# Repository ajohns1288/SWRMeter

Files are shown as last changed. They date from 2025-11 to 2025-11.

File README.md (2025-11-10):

# SWRMeter
PCB files, 3D printing files, and Arduino program to replace the traditional crossed needles SWR meter.

This project was originally done to replace the crossed needle meter on my LDG AT-11MP Tuner, as the meter was broken and replacement parts no longer available.



# To Calibrate
1: Compile with _CALIBRATE_SHOW_COUNTS == 1

2: Attach meter to DUT, transmit into dummy load using FM at 5W and record number on display.

3: Repeat for power values listed in LUT_FWD[] (you can extrapolate if your transmitter only goes so high)

4: Transmit backwards (INTO antenna port with dummy load on TX port) and record number for Ref Pwr. (May want to limit power and extrapolate)

5: Enter recorded values into LUT_FWD[] and LUT_REF[], set _CALIBRATE_SHOW_COUNTS == 0, and compile.

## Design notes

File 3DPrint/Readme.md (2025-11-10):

# 3D Print Files
Both the STLs and FreeCAD FCStd are prpvided

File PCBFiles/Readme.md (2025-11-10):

# PCB Files
This should be everything needed to get a PCB fabbed.

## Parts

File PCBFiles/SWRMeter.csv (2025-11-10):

Comment | Designator | Footprint
10 | R10,R9 | R_0603_1608Metric
0.1u | C10,C9,C8,C7,C4 | C_0603_1608Metric
INA190A1 | U4,U3 | SOT-363_SC-70-6_Handsoldering
10k | R8,R7 | R_0603_1608Metric
500 | R6,R5 | R_0603_1608Metric
22n | C6,C5 | C_0603_1608Metric
AMS1117-5.0 | U1 | SOT-223-3_TabPin2
500 | RV2,RV1 | Potentiometer_Bourns_3314J_Vertical
100 | R4,R3,R2,R1 | R_0603_1608Metric
10u | C3,C2,C1 | CP_EIA-3216-12_Kemet-S

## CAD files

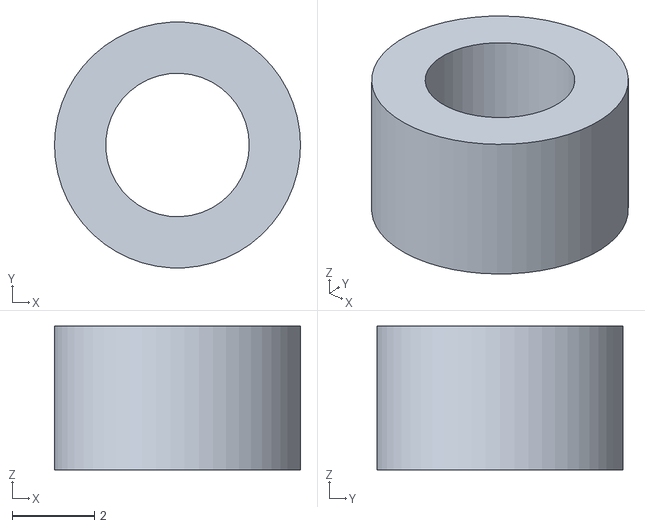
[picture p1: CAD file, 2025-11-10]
3DPrint/SWR-MeterSpacer.stl
6.00 x 5.99 x 3.50

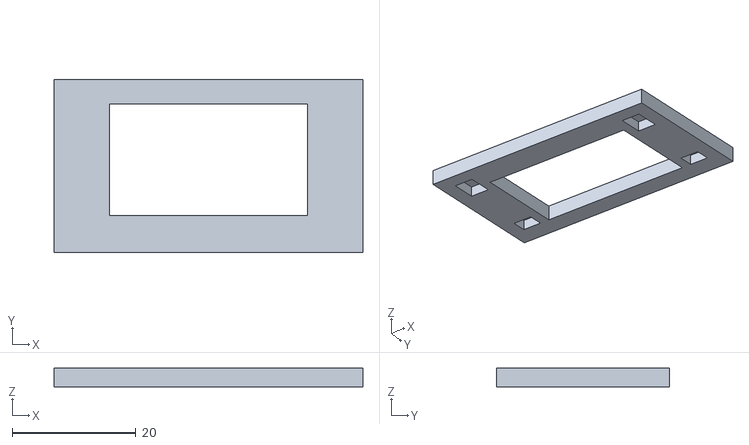
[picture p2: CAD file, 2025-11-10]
3DPrint/SWR-MeterFt.stl
50.0 x 28.0 x 3.00

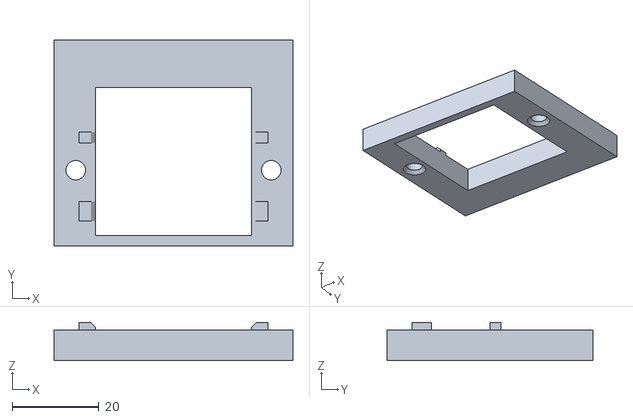
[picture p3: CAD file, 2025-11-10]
3DPrint/SWR-MeterBody.stl
55.0 x 47.5 x 8.75

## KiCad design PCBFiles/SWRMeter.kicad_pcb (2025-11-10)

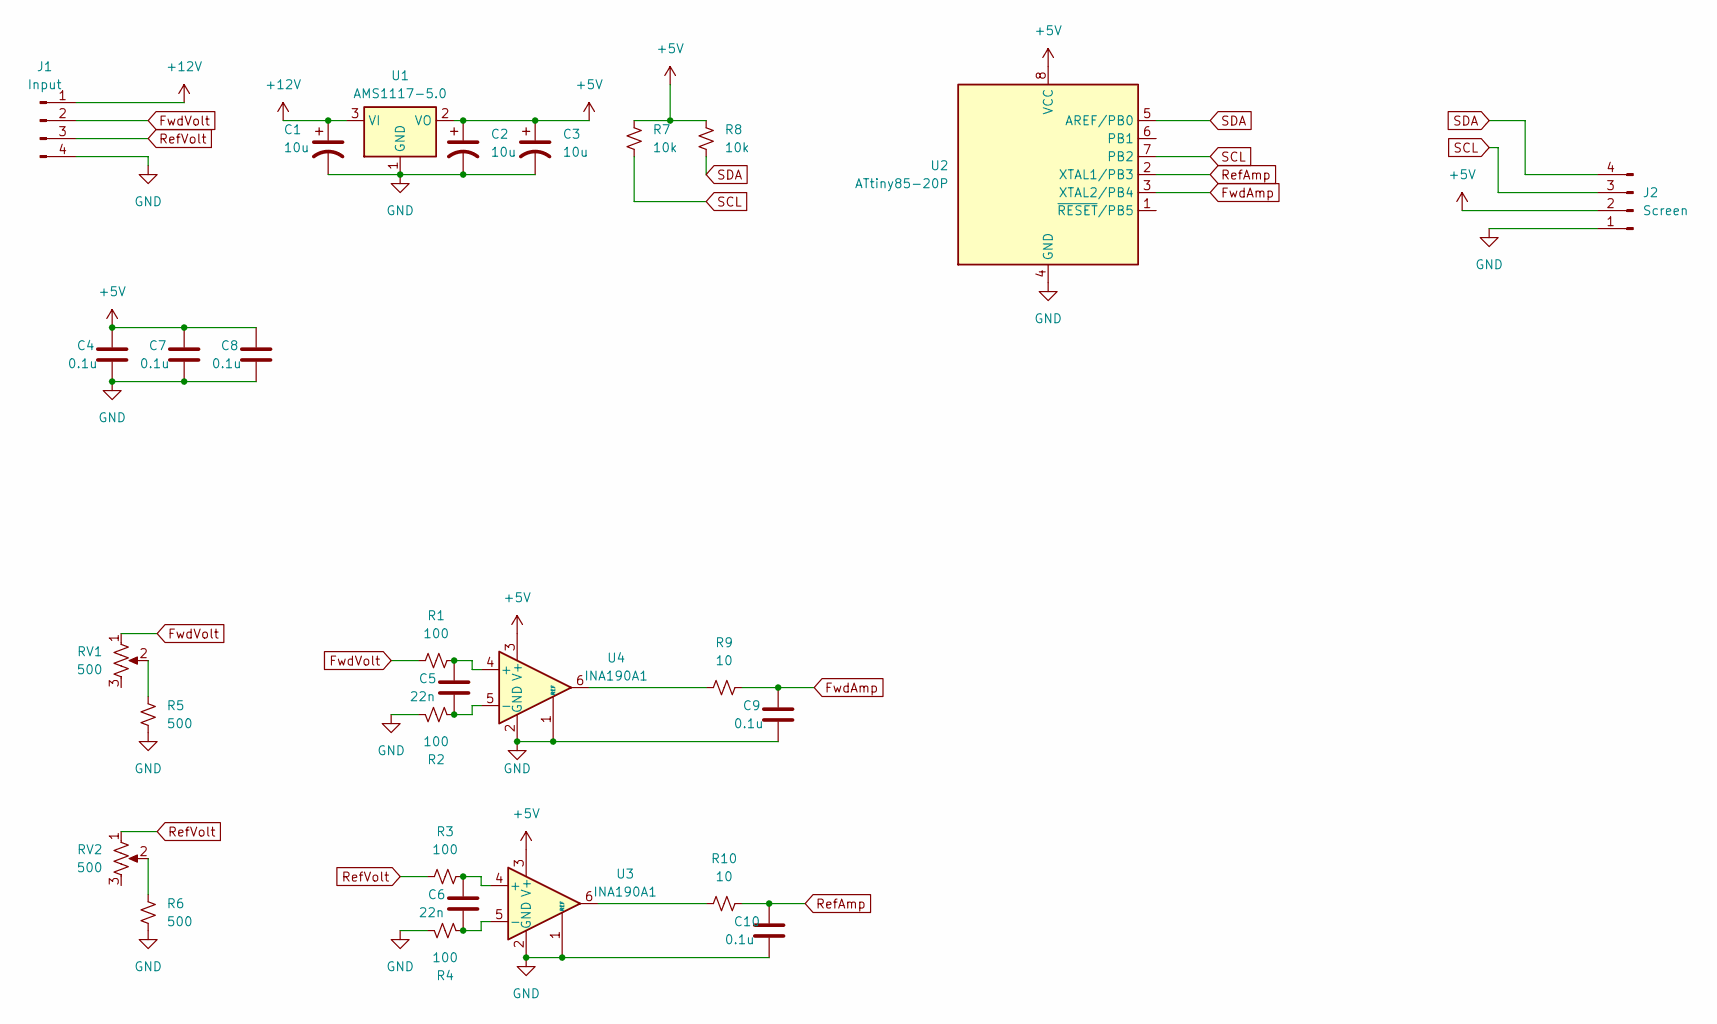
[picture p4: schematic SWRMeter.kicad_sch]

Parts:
C1, C2, C3: 10u; CP_EIA-3216-12_Kemet-S
C4, C7, C8, C9, C10: 0.1u; C_0603_1608Metric
C5, C6: 22n; C_0603_1608Metric
J1: Input; PinHeader_1x04_P2.54mm_Vertical
J2: Screen; PinHeader_1x04_P2.54mm_Vertical
R1, R2, R3, R4: 100; R_0603_1608Metric
R5, R6: 500; R_0603_1608Metric
R7, R8: 10k; R_0603_1608Metric
R9, R10: 10; R_0603_1608Metric
RV1, RV2: 500; Potentiometer_Bourns_3314J_Vertical
U1: AMS1117-5.0; SOT-223-3_TabPin2
U2: ATtiny85-20P; DIP-8_W7.62mm
U3, U4: INA190A1; SOT-363_SC-70-6_Handsoldering

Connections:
+5V: C2.1, C3.1, C4.2, C7.2, C8.2, J2.2, R7.1, R8.1, U1.2 (VO), U2.8 (VCC), U3.3 (V+), U4.3 (V+)
+12V: C1.1, J1.1, U1.3 (VI)
FwdAmp: C9.2, R9.2, U2.3 (XTAL2/PB4)
FwdVolt: J1.2, R1.1, RV1.1
GND: C1.2, C2.2, C3.2, C4.1, C7.1, C8.1, C9.1, C10.1, J1.4, J2.1, R2.1, R4.1, R5.2, R6.2, U1.1 (GND), U2.4 (GND), U3.1 (REF), U3.2 (GND), U4.1 (REF), U4.2 (GND)
unnamed: R5.1, RV1.2
unnamed: R6.1, RV2.2
unnamed: R9.1, U4.6
unnamed: R10.1, U3.6
unnamed: C6.2, R3.2, U3.4 (+)
unnamed: C6.1, R4.2, U3.5 (-)
unnamed: C5.2, R1.2, U4.4 (+)
unnamed: C5.1, R2.2, U4.5 (-)
RefAmp: C10.2, R10.2, U2.2 (XTAL1/PB3)
RefVolt: J1.3, R3.1, RV2.1
SCL: J2.3, R7.2, U2.7 (PB2)
SDA: J2.4, R8.2, U2.5 (AREF/PB0)

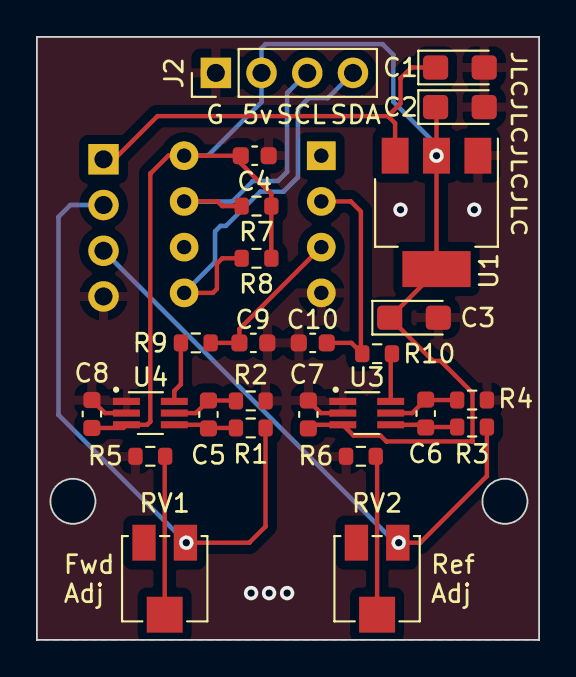
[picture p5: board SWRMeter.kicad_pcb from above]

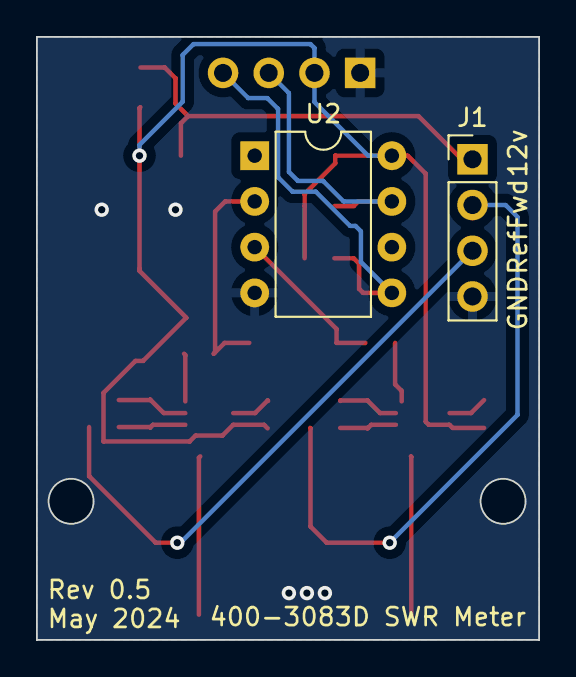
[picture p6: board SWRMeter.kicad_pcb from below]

Board: 2 copper layers, 27.9 x 33.5 mm, 28 parts (2 on the bottom side), 17 nets.

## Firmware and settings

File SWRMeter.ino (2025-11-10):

/*
  Project: Digital SWR/Power Meter
  SWRMeter.ino: Code that reads voltages, calculates power/SWR based on those voltages, then displays on screen

  NOTE: This was designed to run on an ATTiny85 with the latest ATTiny core. It will not compile without the latest ATTinyCore.

    Copyright (C) 2024, Andrew Johnson AJohns1288@Gmail.com

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
    You should have received a copy of the GNU General Public License
    along with this program.  If not, see <https://www.gnu.org/licenses/>.
*/

//Include needed files
#include "TinySH1106.h" //Display library
#include "font.h" //Fonts for display library
#include "LUT.h"  //Lookup table function 

//Flag to display counts instead of power. Used for setting the calibration curve
#define _CALIBRATE_SHOW_COUNTS 0

//Hardware defines/////////////////////////
//Pins to use for measurement
#define FWD_PWR_PIN A2
#define REF_PWR_PIN A3

//Voltage limits
#define MIN_VAL 8  //Min clip on voltage, in ADC counts
///////////////////////////////////////////


//DSP defines//////////////////////////////
//Note: These DSP functions were put in as an experimental exercise. They can be adjusted as needed

#define _DSP_USE_MULTI_SAMPLE 1   //Enabled: ADC read takes 5 samples, excludes extremes, and averages for each reading. Disabled: One sample per reading
#define _DSP_USE_WINDOW_AVG 1     //Enabled: ADC read is averaged across previous 5 readings. Disabled: ADC read is not averaged (Averaging takes place after read)
#define _DSP_USE_EWMA_FILTER 1    //Enabled: ADC read is filtered. Disabled: ADC read is not filtered. (Filtering takes place after averaging)
#define _DSP_USE_ADC_NOISE_RED 1  //Enabled: ADC reads will use the noise reduction feature (sleep during conversion), Disabled: ADC reads will occur with all CPU running
#define _DSP_USE_DITHER 1         //Enabled: ADC is read twice in a row, one bit is added, then sum divded by 2. This helps with single bit noise, Disabled: ADC is read once.
#define _DSP_PEAK_HOLD_TIME 3000  //Amount of time, in ms, that the peak value will be held on the display
#define _DSP_PEAK_HOLD_DEC 50     //Rate that the display value will decay to the current value after the hold time expires
#define ADC_TIME 250              //Minimum sample rate, in us, that the ADCs are read. Note that this is the minimum, actual readings may take longer.

//Filter constants for EWMA filter in fixed 10e-1 point(8=0.800)
#define FWD_FILTER_CONST 3
#define REF_FILTER_CONST 3
////////////////////////////////////////////


//Display defines///////////////////////////
//Full scale power in watts
#define FWD_PWR_FS 300
#define REF_PWR_FS 60

//Screen Refresh Rate
#define UPDATE_TIME 250  //In milliseconds
////////////////////////////////////////////

#if _DSP_USE_ADC_NOISE_RED
#include <avr/sleep.h>  // Sleep Modes
EMPTY_INTERRUPT(ADC_vect);
#endif


//Calibration table for FWD Pwr (counts to Watts x10)
const unsigned int LUT_FWD[] PROGMEM= {10, \
                10, 0, \
                88, 5, \
                118, 10, \
                180, 30, \
                213, 40, \
                273, 60, \
                300, 70, \
                350, 90, \
                695, 200, \
                1000, 300
              };

//Calibration table for Ref Pwr (counts to Wattsx10)
const unsigned int LUT_REF[] PROGMEM= {10, \
                10, 00, \
                88, 10, \
                118, 20, \
                180, 60, \
                213, 80, \
                273, 120, \
                300, 140, \
                350, 180, \
                695, 400, \
                1000, 600
              };


//Display object
TinySH1106 display(0x3c);

//char constant buffers
const char text_FWD[] = { 'F', 'W', 'D', 0x20 };
const char text_REF[] = { 'R', 'E', 'F', 0x20 };
const char text_PWR[] = { 'P', 'W', 'R', ':', 0x20, 0 };
const char text_SWR[] = { 'S', 'W', 'R', ':', 0x20, 0 };

//Char buffers for display values
char buf_PWR_val[] = { 0x20, 0x20, 0x20, 0x20, 0 };
char buf_REF_val[] = { 0x20, 0x20, 0x20, 0x20, 0 };
char buf_SWR_val[] = { '1', '.', '0', '0', 0 };

//Instantaneous/filtered ADC reads (in counts)
int fwdPwrInst = 0;
int refPwrInst = 0;
int fwdPwrFilt = 0;
int refPwrFilt = 0;

//Filter buffer - Compile the buffers out to save memory if unused
#if _DSP_USE_MULTI_SAMPLE
int filtBuf[] = { 0, 0, 0, 0, 0 };
#endif

//Windowed Average buffer - Compile the buffers out to save memory if unused
#if _DSP_USE_WINDOW_AVG
int fwdAvgBuf[] = { MIN_VAL, MIN_VAL, MIN_VAL, MIN_VAL, MIN_VAL };
int refAvgBuf[] = { MIN_VAL, MIN_VAL, MIN_VAL, MIN_VAL, MIN_VAL };
uint8_t avgIndx = 0;
#endif

//Display values - integer representation
int swrVal = 100;    //SWR x 100
int fwdDispVal = 0;  //Watts x1
int refDispVal = 0;  //Watts x1

//Timers
long dispUpdateTmr = 0; //Display refresh rate
long ADCTmr = 0; //ADC Sample rate
long FWDPeakHold=0; //Peak hold for FWD power
long REFPeakHold=0; //Peak hold for reflected power.


void setup() {

  analogRead(FWD_PWR_PIN); //Initialize A2D

  //Start display and set up splash screen
  display.begin();
  display.clear();
  splash();
  delay(1000);
  display.clear();

  //Set up static parts of display
  display.setCursor(0, 0);
  display.print(text_FWD);
  display.setCursor(40, 0);
  display.print(text_PWR);
  display.setCursor(0, 2);
  display.print(text_REF);
  display.setCursor(40, 2);
  display.print(text_PWR);
  display.setCursor(16, 6);
  display.print(text_SWR);
}

void loop() {
  //Update display if it is time
  if (millis() - dispUpdateTmr > UPDATE_TIME) {
    dispUpdateTmr = millis(); //Reset timer

    swrVal = getSWR(fwdDispVal, refDispVal); //Ger SWR value from fwd and ref powers


    //If we are in calibration mode, set display value to ADC counts (only last 3 digits will show)
    #if _CALIBRATE_SHOW_COUNTS
    fwdDispVal = fwdPwrFilt;
    refDispVal = refPwrFilt;
    #else
    //If we are in normal mode, convert voltage to power
    voltToPwr();
    #endif

    //Update screen with updated values
    updateScreen();
  }


  //Sample ADC if it is time
  if(micros()-ADCTmr>ADC_TIME)
  {
    ADCTmr=micros();
    readPwrADC();
  }
  
}

void swr2Char(int i, char *buf) {
  
  //Get the character that corresponds with each place in the input
  char ones = i % 10 + 0x30;
  char tens = (i / 10) % 10 + 0x30;
  char hund = (i / 100) % 10 + 0x30;

  //set the text buffers based on how big the SWR is
  if (i < 100) {
    buf[0] = 'E';
    buf[1] = 'R';
    buf[2] = 'R';
    buf[3] = 0x20;
  } else if (i >= 600) {
    buf[0] = 'H';
    buf[1] = 'I';
    buf[2] = 0x20;
    buf[3] = 0x20;
  } else {
    buf[0] = hund;
    buf[1] = '.';
    buf[2] = tens;
    buf[3] = ones;
  }
}

void pwr2Char(int i, char *buf) {
  
  //Get the character that corresponds with each place in the input
  char ones = i % 10 + 0x30;
  char tens = (i / 10) % 10 + 0x30;
  char hund = (i / 100) % 10 + 0x30;


  //set the buffers based on how big the power is
  if (i < 10) {
    buf[0] = ones;
    buf[1] = 'W';
    buf[2] = 0x20;
    buf[3] = 0x20;
  } else if (i < 100) {
    buf[0] = tens;
    buf[1] = ones;
    buf[2] = 'W';
    buf[3] = 0x20;
  } else {
    buf[0] = hund;
    buf[1] = tens;
    buf[2] = ones;
    buf[3] = 'W';
  }
}

void splash() {
  display.drawBitmap(bitmap1, 40, 18);
}

void updateScreen() {
  //Convert values to corresponding characters
  pwr2Char(fwdDispVal, buf_PWR_val);
  pwr2Char(refDispVal, buf_REF_val);
  swr2Char(swrVal, buf_SWR_val);

  //Set print position and print the updated characters
  display.setCursor(81, 2);
  display.print(buf_REF_val);
  display.setCursor(81, 0);
  display.print(buf_PWR_val);
  display.setCursor(52, 6);
  display.print(buf_SWR_val);
}

int getADCReading(byte port) 
{

  //Wrapper function to get ADC readings
  //ATTinycore's newest version allows analogRead to use the onboard ADC noise reduction function
  //If dithering is turned on, function will take two readings, add a bit, then divide by two. This has the affect of helping with single bit noise

//Variable to store first read when using dithering  
int read1=0;

//If ATTIny, use the noise reduction read in newest ATTiny core.
#if (AVR_ARCH==2||AVR_ARCH==25)
  #if _DSP_USE_DITHER
  read1=_analogRead(port, _DSP_USE_ADC_NOISE_RED);
  return (read1+_analogRead(port, _DSP_USE_ADC_NOISE_RED))+1)/2;
  #else
  return _analogRead(port, _DSP_USE_ADC_NOISE_RED);
  #endif
#else
//For Normal arduino, ADC noise reduction not possible
  #if _DSP_USE_DITHER
  read1=analogRead(port);
  return (read1+analogRead(port)+1)/2;
  #else
  return analogRead(port);
  #endif
#endif
 //End _DSP_USE_ADC_NOISE_RED
}

void readPwrADC() {
//function to read in voltages and filter them
#if _DSP_USE_MULTI_SAMPLE

  int maxRead = 0;
  int minRead = 1024;

  for (int i = 0; i < 5; i++) {
    fwdPwrInst = getADCReading(FWD_PWR_PIN);
    filtBuf[i] = fwdPwrInst;

    if (fwdPwrInst > maxRead) {
      maxRead = fwdPwrInst;
    } else if (fwdPwrInst < minRead) {
      minRead = fwdPwrInst;
    }
  }
  fwdPwrInst = ((filtBuf[0] + filtBuf[1] + filtBuf[2] + filtBuf[3] + filtBuf[4]) - minRead - maxRead) / 3;

  //Reset min/max
  maxRead = 0;
  minRead = 1024;
  for (int i = 0; i < 5; i++) {
    refPwrInst = getADCReading(REF_PWR_PIN);
    filtBuf[i] = refPwrInst;

    if (refPwrInst > maxRead) {
      maxRead = refPwrInst;
    } else if (refPwrInst < minRead) {
      minRead = refPwrInst;
    }
  }
  refPwrInst = ((filtBuf[0] + filtBuf[1] + filtBuf[2] + filtBuf[3] + filtBuf[4]) - minRead - maxRead) / 3;


#else  //just take one sample
  fwdPwrInst = getADCReading(FWD_PWR_PIN);
  refPwrInst = getADCReading(REF_PWR_PIN);
#endif

#if _DSP_USE_WINDOW_AVG
//Window average the last 5 samples excluding outliers
  fwdAvgBuf[avgIndx] = fwdPwrInst;
  refAvgBuf[avgIndx] = refPwrInst;

  avgIndx > 4 ? avgIndx = 0 : avgIndx++;

  int minRef = refAvgBuf[0];
  int maxRef = refAvgBuf[0];
  int minFwd = fwdAvgBuf[0];
  int maxFwd = fwdAvgBuf[0];

  int refSum = refAvgBuf[0];
  int fwdSum = fwdAvgBuf[0];

  for (int i = 1; i < 5; i++) {
    maxRef = max(refAvgBuf[i], maxRef);
    minRef = min(refAvgBuf[i], minRef);

    maxFwd = max(fwdAvgBuf[i], maxFwd);
    minFwd = min(fwdAvgBuf[i], minFwd);

    fwdSum += fwdAvgBuf[i];
    refSum += refAvgBuf[i];
  }

  refPwrInst = (refSum - minRef - maxRef) / 3;
  fwdPwrInst = (fwdSum - minFwd - maxFwd) / 3;
#endif // End USE_WINDOW_AVG

#if _DSP_USE_EWMA_FILTER
  //EWMA filter using integer math (alpha x10)
  fwdPwrFilt = (FWD_FILTER_CONST * fwdPwrInst) + ((10 - FWD_FILTER_CONST) * fwdPwrFilt);
  refPwrFilt = (REF_FILTER_CONST * refPwrInst) + ((10 - REF_FILTER_CONST) * refPwrFilt);
  //divide by 10 because we scaled up by 10 for the lines above
  fwdPwrFilt /= 10;
  refPwrFilt /= 10;
#else  //No filtering, just use instantaneous value
  fwdPwrFilt = fwdPwrInst;
  refPwrFilt = refPwrInst;
#endif
}

int voltToPwr()
{
  //Variable to hold lookup table result.
  int tmp=0;
  
  //If filtered power voltage value is over the min voltage, look up voltage in table, otherwise set power to 0
  (refPwrFilt<MIN_VAL)?refDispVal = 0:tmp = lookupTable(LUT_REF,refPwrFilt);


  //Peak and hold function
  if(tmp>refDispVal)//If current reading greater than whats on display
  {
    refDispVal=tmp; //Set display value if current reading is higher
    REFPeakHold=millis(); //Restart timer
  }
  else if(millis()-REFPeakHold>_DSP_PEAK_HOLD_TIME) //If current reading less than display and hold time expires
  {
    refDispVal-=_DSP_PEAK_HOLD_DEC; //Decrement display value by calibratable amount
    refDispVal=max(refDispVal,tmp); //Set display value to max of decremented value or current reading.
  } //Otherwise do nothing (leave display value as is)

  //If filtered power voltage value is over the min voltage, look up voltage in table, otherwise set power to 0
  (fwdPwrFilt<MIN_VAL)?fwdDispVal = 0:tmp = lookupTable(LUT_FWD,fwdPwrFilt);


  //Peak and hold function for Fwd power
  if(tmp>fwdDispVal)
  {
    fwdDispVal=tmp;
    FWDPeakHold=millis();
  }
  else if(millis()-FWDPeakHold>_DSP_PEAK_HOLD_TIME)
  {
    fwdDispVal-=_DSP_PEAK_HOLD_DEC;
    fwdDispVal=max(fwdDispVal,tmp);
  }

}


int getSWR(int fwdPwr, int refPwr) {
  //calculate the SWR without using floats, returns SWR x 100.
  if (refPwr * 2 > fwdPwr) {
    return 600;  //just send 6 if SWR is too high;
  } else if (refPwr == 0) {
    return 100;  //send 1 if no reflected power
  }


  //Calculate reflection coeff - We rescale by 1024 and 100 to get more precision in the sqrt function, since we are using fixed point math
  //Note that 1024 and 100 rescales will change to 32 and 10 after the square root due to distributive property.
  unsigned int tmp = (refPwr * 1024) / fwdPwr;  //rescale by 1024 (32^2)
  tmp = 100 * tmp;                              //rescale by 100 (10^2)
  tmp = intSqrt(tmp);                           // this will give you closest integer sqrt of the rescaled value above
  tmp = tmp * 100;                              //rescale by another 100 (+10*32 from before sqrt)
  tmp = tmp / 32;                               //this gives reflection coef *1000

  //SWR = (1+gamma)/(1-gamma) (x1000 due to scale above)
  unsigned int swrNum = (10 * (1000 + tmp));  //1 +gamma term
  return swrNum / ((1000 - tmp) / 10);        //divde by 1-gamma term
}

unsigned int intSqrt(int s) {
  //quick and dirty sqrt function to avoid floats
  int guess = (s >> 7) + 6;  //pick initial guess based on s

  for (uint8_t i = 0; i < 4; i++) { //4 iterations of newtons method to get approximate square root.
    guess = (guess + (s / guess));  //newtons method
    guess >>= 1;                    //divide by 2
  }

  return guess;
}

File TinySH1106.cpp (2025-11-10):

/*
  Project: Digital SWR/Power Meter
  TinySH1106.cpp: Library to interface with SH1106. Goal is to minimize RAM usage to be compatable with ATTiny
  Andrew Johnson AJohns1288@Gmail.com

  Adapted from:
  Tiny Graphics Library v3 - see http://www.technoblogy.com/show?23OS
  David Johnson-Davies - www.technoblogy.com - 23rd September 2018

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
    You should have received a copy of the GNU General Public License
    along with this program.  If not, see <https://www.gnu.org/licenses/>.
*/

#include "TinySH1106.h"
#include "font.h"

char TinySH1106::ReverseByte (char x) {
  x = ((x >> 1) & 0x55) | ((x << 1) & 0xaa);
  x = ((x >> 2) & 0x33) | ((x << 2) & 0xcc);
  x = ((x >> 4) & 0x0f) | ((x << 4) & 0xf0);
  return x;    
}

void TinySH1106::initDisplay () {
  sendCommand(DISPLAY_OFF); 
  sendCommand(SEG_REMAP_REV);  // Flip horizontal
  sendCommand(SET_SCAN_DEC);  // Flip horizontal
  sendCommand(DISPLAY_ON);  // Display on
  setMuxRatio(0x3F);
  setContrast(0xCF);
  setOffset(DEFAULT_OFFSET);
}

// Plot point x,y into buffer if in current slice
// void TinySH1106::PlotPoint (int x, int y) {
//   Wire.beginTransmission(wireAddr);
//   sendCommand(0x00 + ((x + 2) & 0x0F));        // Column low nibble
//   sendCommand(0x10 + ((x + 2)>>4));            // Column high nibble
//   sendCommand(0xB0 + (y >> 3));                // Page
//   sendCommand(0xE0);                           // Read modify write
//   Wire.write(SINGLE_DATA);
//   Wire.endTransmission();
//   Wire.requestFrom(wireAddr, 2);
//   Wire.read();                            // Dummy read
//   int j = Wire.read();
//   Wire.beginTransmission(wireAddr);
//   Wire.write(SINGLE_DATA);
//   Wire.write((1<<(y & 0x07)) | j);
//   sendCommand(0xEE);                           // Cancel read modify write
//   Wire.endTransmission();
// }

void TinySH1106::drawBitmap(const unsigned char s[], uint8_t x, uint8_t y)
{

  //Macros for register settings, this is done since pages and offsets are limited to 7, so we can combine to save memory
  #define SET_PAGE_OFFSET(o) drawBitmapReg|=(o & 0x07)
  #define GET_PAGE_OFFSET (drawBitmapReg & 0x07)
  #define SET_PAGE_START(o) drawBitmapReg|=(((y/8) & 0x07)<<4)
  #define GET_PAGE_START ((drawBitmapReg & 0x70)>>4)
  #define SET_PAGE_SPLIT drawBitmapReg|=(0x08)
  #define CLEAR_PAGE_SPLIT drawBitmapReg&=~(0x08)
  #define GET_PAGE_SPLIT (drawBitmapReg&0x08)

  uint8_t drawBitmapReg=0; //Register to store offset in page, start page, and if bitmap is split across n+1 pages. 
  //Format: xsss pooo | x: not used, sss: start page, p: split page, ooo: offset

  SET_PAGE_OFFSET(y);
  SET_PAGE_START(y);

  uint8_t bmpWidth=s[0]; //bitmap width
  uint8_t bmpHeight=s[1]; //bitmap height
  uint8_t bits=0; //var to store progmem reads

  uint8_t pagesNeeded=(s[1]-1)/8; //Number of pages needed to display bitmap, zero indexed 

  GET_PAGE_OFFSET==0?pagesNeeded++:pagesNeeded+=2; //change to one indexed, add another page due to offset if needed
  GET_PAGE_OFFSET==0?CLEAR_PAGE_SPLIT:SET_PAGE_SPLIT;

  for (uint8_t p = GET_PAGE_START; p < GET_PAGE_START+pagesNeeded; p++) { //Loop for each page

    setPage((p)); //Set page to active page
    setCol(x);     //Set column to active
    sendCommand(RMW);

    for (uint8_t col=0; col<s[0]; col++) {
      uint8_t j=readData();
      if(p == (GET_PAGE_START))//first page, only one bitmap row needed
      {
          bits=pgm_read_byte(&s[(col+2)]); //get bits
          sendData(bits<<GET_PAGE_OFFSET);//Left shift shifts down by H
      }
      else if(p < (GET_PAGE_START+pagesNeeded-1))//not first not last, will need two bitmap rows, offset and ORd
      {
        bits=(pgm_read_byte(&s[(col+2)+((p-GET_PAGE_START)-1)*(s[0])]))>>(8-GET_PAGE_OFFSET); //Get above row offset
        bits|=((pgm_read_byte(&s[(col+2)+((p-GET_PAGE_START))*(s[0])]))<<GET_PAGE_OFFSET)&0xFF; //get current row offset

        sendData(bits);

      }
      else //last page
      {
          if(GET_PAGE_SPLIT) //bitmap not aligned to pages, need to shift
          {
            bits=(pgm_read_byte(&s[(col+2)+((p-GET_PAGE_START)-1)*(s[0])]));
            sendData(bits>>(8-GET_PAGE_OFFSET));
          }
          else //bitmap aligned to page bounds, no need to shift
          {
            bits=(pgm_read_byte(&s[(col+2)+((p-GET_PAGE_START))*(s[0])]));
            sendData(bits);
          }
      }
    }
    sendCommand(RMW_END); 
  }

  #undef SET_PAGE_OFFSET
  #undef GET_PAGE_OFFSET
  #undef SET_PAGE_START
  #undef GET_PAGE_START
  #undef SET_PAGE_SPLIT
  #undef CLEAR_PAGE_SPLIT
  #undef GET_PAGE_SPLIT
}

void TinySH1106::drawChar(const unsigned char c, uint8_t x, uint8_t y)
{

  //Macros for register settings, this is done since pages and offsets are limited to 7, so we can combine to save memory
  #define SET_PAGE_OFFSET(o) drawBitmapReg|=(o & 0x07)
  #define GET_PAGE_OFFSET (drawBitmapReg & 0x07)
  #define SET_PAGE_START(o) drawBitmapReg|=(((y/8) & 0x07)<<4)
  #define GET_PAGE_START ((drawBitmapReg & 0x70)>>4)
  #define SET_PAGE_SPLIT drawBitmapReg|=(0x08)
  #define CLEAR_PAGE_SPLIT drawBitmapReg&=~(0x08)
  #define GET_PAGE_SPLIT (drawBitmapReg&0x08)

  uint8_t drawBitmapReg=0; //Register to store offset in page, start page, and if bitmap is split across n+1 pages. 
  //Format: xsss pooo | x: not used, sss: start page, p: split page, ooo: offset

  SET_PAGE_OFFSET(y);
  SET_PAGE_START(y);

  uint8_t bmpWidth=FONT_WIDTH; //bitmap width
  uint8_t bmpHeight=FONT_HEIGHT; //bitmap height
  uint8_t bits=0; //var to store progmem reads

  uint8_t pagesNeeded=(FONT_HEIGHT-1)/8; //Number of pages needed to display bitmap, zero indexed 

  GET_PAGE_OFFSET==0?pagesNeeded++:pagesNeeded+=2; //change to one indexed, add another page due to offset if needed
  GET_PAGE_OFFSET==0?CLEAR_PAGE_SPLIT:SET_PAGE_SPLIT;

  for (uint8_t p = GET_PAGE_START; p < GET_PAGE_START+pagesNeeded; p++) { //Loop for each page

    setPage(p); //Set page to active page
    setCol(x);     //Set column to active
    sendCommand(RMW);

    for (uint8_t col=0; col<FONT_WIDTH; col++) {
      uint8_t j=readData();
      if(p == (GET_PAGE_START))//first page, only one bitmap row needed
      {
          bits=pgm_read_byte(&CharMap[CHAR_INDEX(c)][col]); //get bits
          sendData(bits<<GET_PAGE_OFFSET);//Left shift shifts down by H
      }
      else if(p < (GET_PAGE_START+pagesNeeded-1))//not first not last, will need two bitmap rows, offset and ORd
      {
        bits=(pgm_read_byte(&CharMap[CHAR_INDEX(c)][(col+2)+((p-GET_PAGE_START)-1)*(FONT_WIDTH)]))>>(8-GET_PAGE_OFFSET); //Get above row offset
        bits|=((pgm_read_byte(&CharMap[CHAR_INDEX(c)][(col+2)+((p-GET_PAGE_START))*(FONT_WIDTH)]))<<GET_PAGE_OFFSET)&0xFF; //get current row offset

        sendData(bits);
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

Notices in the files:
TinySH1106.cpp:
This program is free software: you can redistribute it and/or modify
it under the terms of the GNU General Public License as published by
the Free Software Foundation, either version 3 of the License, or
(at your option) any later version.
